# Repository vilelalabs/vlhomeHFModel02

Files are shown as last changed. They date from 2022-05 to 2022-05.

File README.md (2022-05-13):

# VLHOME Hardware Firmware - MODEL 02

Remotely activated device through Wifi connection with a Firebase database.

## Project

This software was developed to be used on ESP8266-12 (4Mb flash) microcontroller to controls a high voltage device and connecting to a physical activated switch.

## Operation

the device can be activated through three ways:

### > Application
Through using dedicated Application:  [VLHome App](https://github.com/vilelalabs/vlhome) 

### > Webpage
Through webpage using the addresses:

|Link |Function|
|:---:|:---:|
|http://device-IPAdress/|home page that confirms the connection|
|http://device-IPAdress/update|update through OTA|
|http://device-IPAdress/toggle|toggles the current state of the device|
|http://device-IPAdress/hostname|shows the host name of the device|

> example: http://192.168.1.225/update

### > Switch

Can be physically actvated bt the switch linked to CON1 (SWITCH) connector onboard (see images) - this connection is optional.

# Installation 

Until now (version: 1.0) its needed to use an auxiliar application from Espressif to connect the device to the local network. The application used is [EspTouch: SmartConfig for ESP ESP8266, ESP32](https://play.google.com/store/apps/details?id=com.khoazero123.iot_esptouch_demo). On it you will need to put the SSID and password information.

After some time the device is found and it shows the IP address, take note to use the webpage activation method, or even to compare to new device configuration screen (*Novo Dispositivo*) through [App](https://github.com/vilelalabs/vlhome).

From this point  **webpage** and **switch** methods can be used already , but on the **App**, you still need use the menu before: 

**Configurações > Dispositivos > Novo > Buscar Novo Dispositivo**

# Folder eaglefiles

In this folder you will find the necessary files for building the hardware board: 

- Eagle project
- Schematic file (SCH)
- Board file (PCB layout) (BRD) (between the two projects - one/two side only capacitor package is different)
- Bill of Materials file (BOM)
- PDF file with a ready-for-printing page with the board layout.
- MODEL_2_Gerber.zip for sent to a professinal fabrication

_* there is two versions for one side cooper and Double Layer  boards, see by file names_
# Images

## Schematic
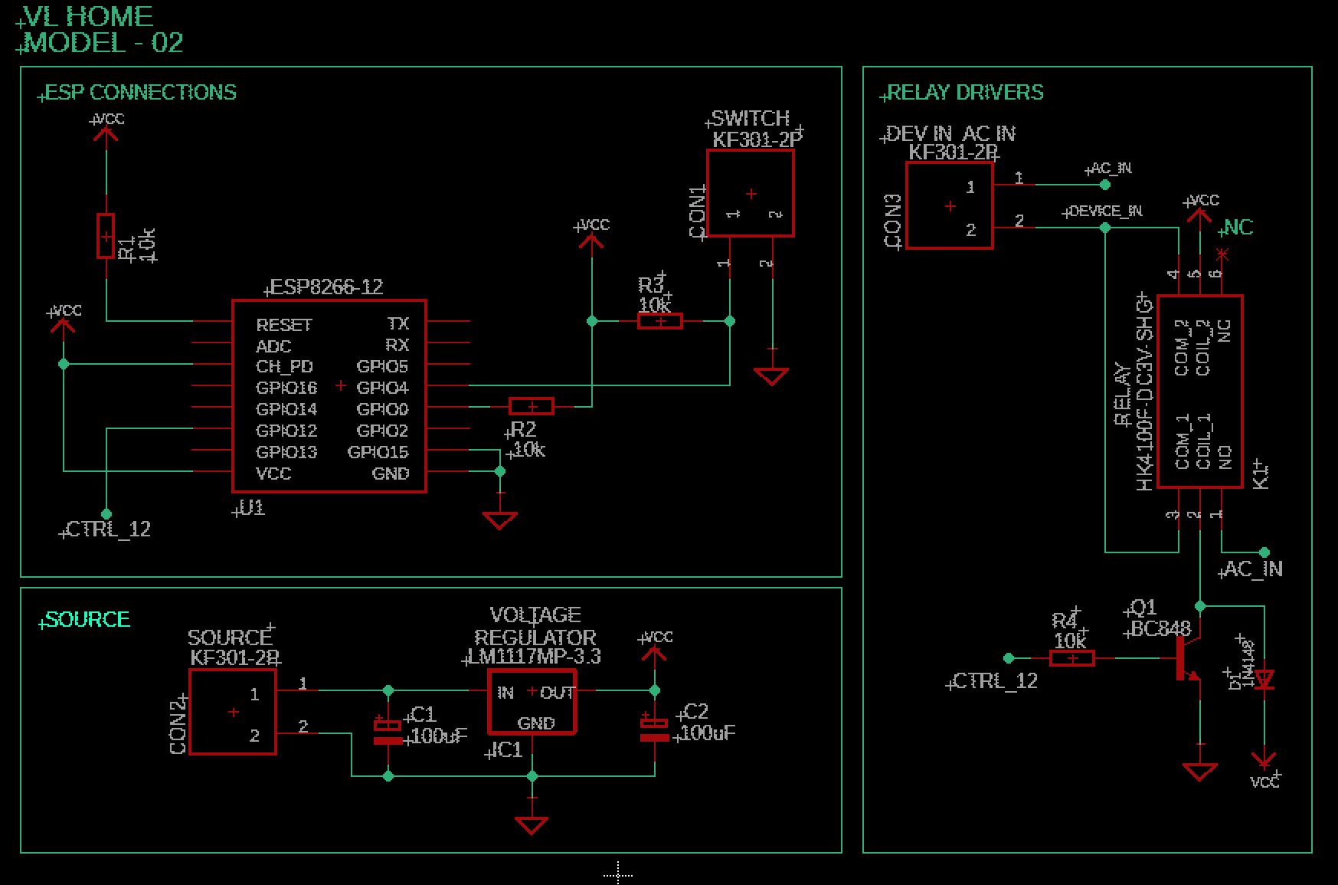
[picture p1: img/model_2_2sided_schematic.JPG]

## Board (PCB)
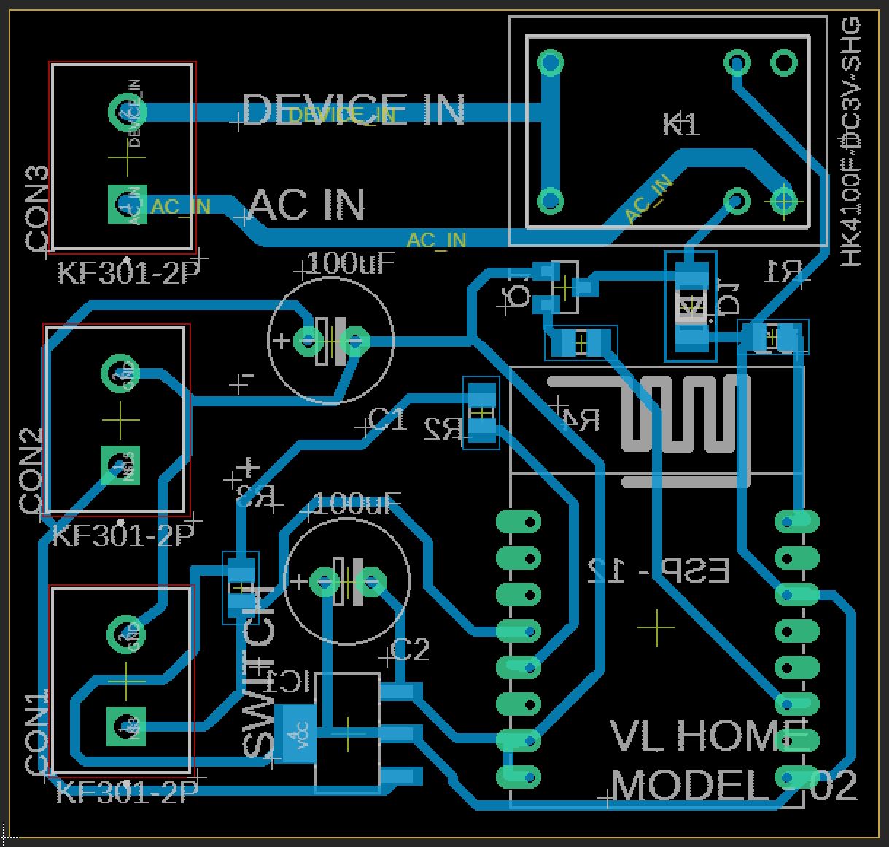
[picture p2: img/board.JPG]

### Double Layer  Board (PCB)
|Top Side |Bottom side|
|:---:|:---:|
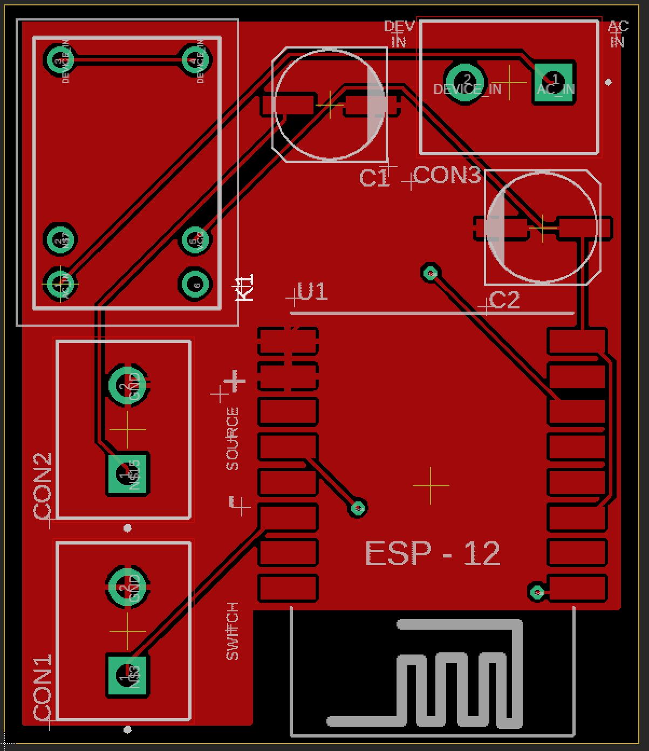
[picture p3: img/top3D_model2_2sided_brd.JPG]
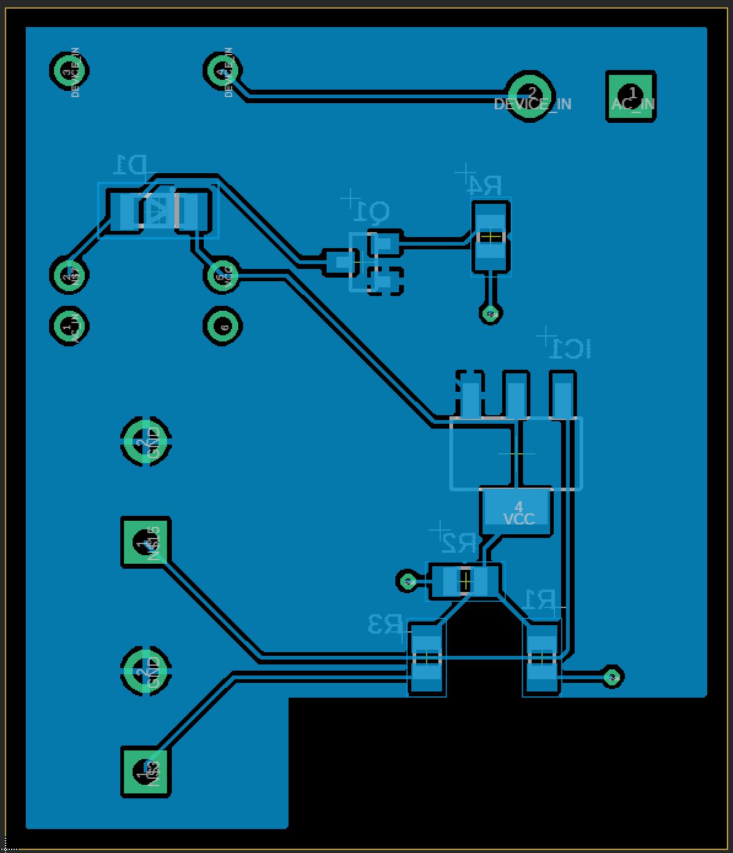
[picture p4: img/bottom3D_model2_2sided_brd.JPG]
|||
## 3D View
|Top Side - Single Cooper |Bottom side - Single Cooper|
|:---:|:---:|
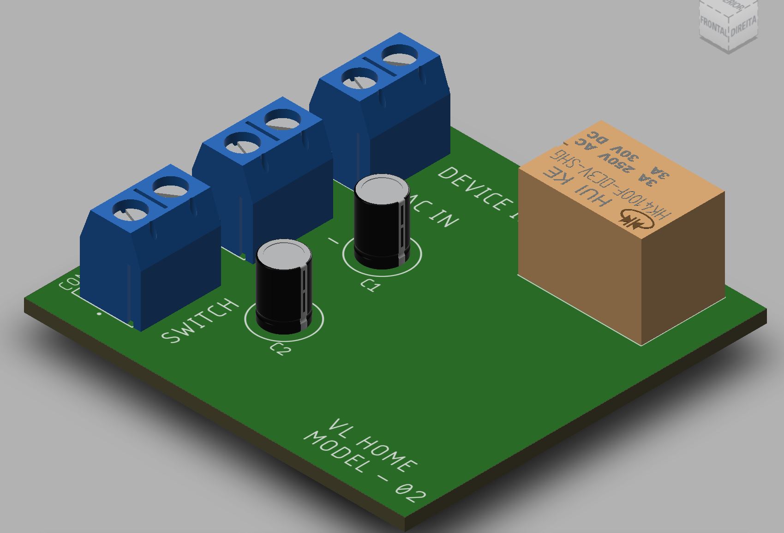
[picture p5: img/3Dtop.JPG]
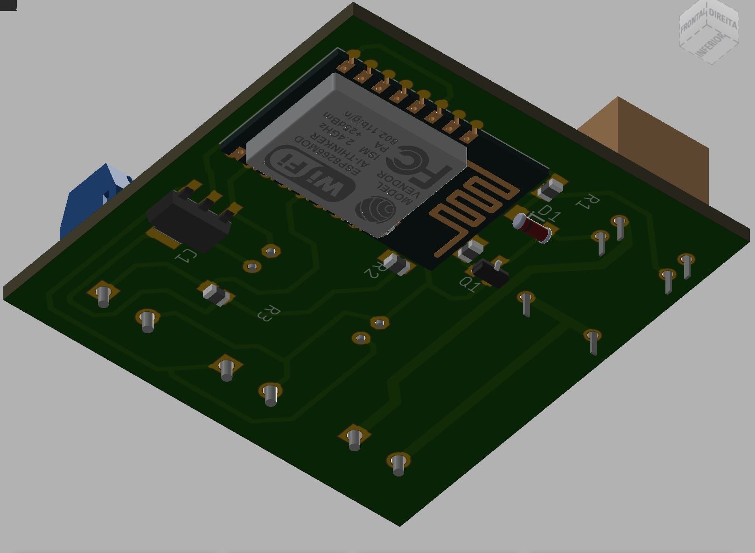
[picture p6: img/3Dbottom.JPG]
|||
|Top Side - Double Layer Cooper|Bottom side - Double Layer Cooper|
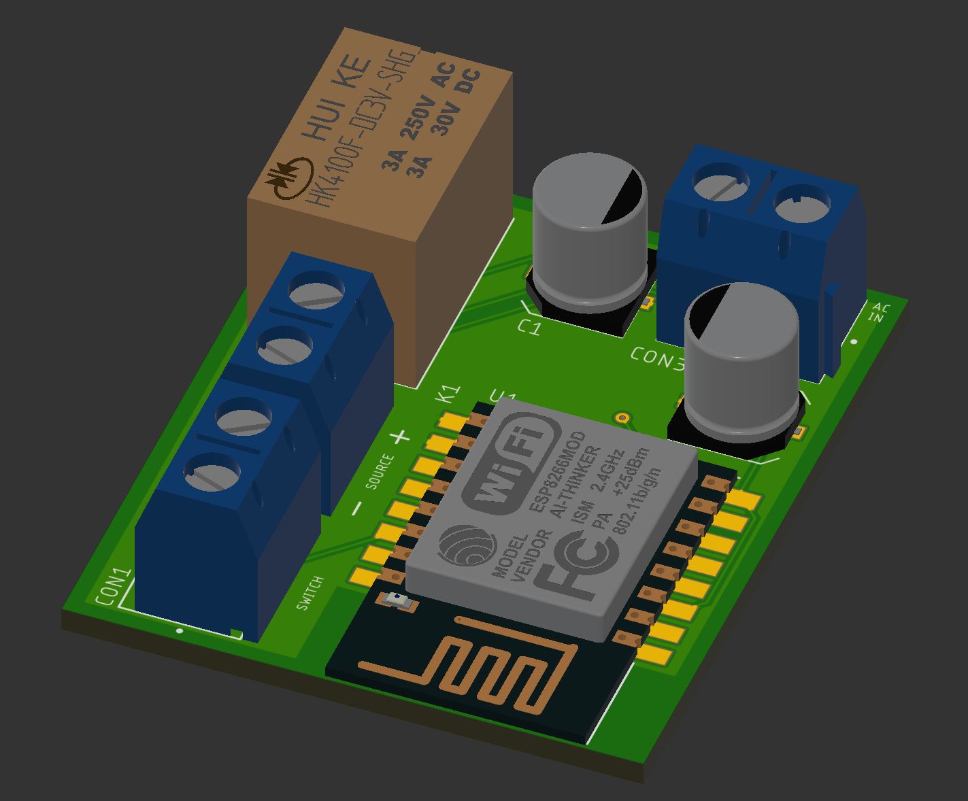
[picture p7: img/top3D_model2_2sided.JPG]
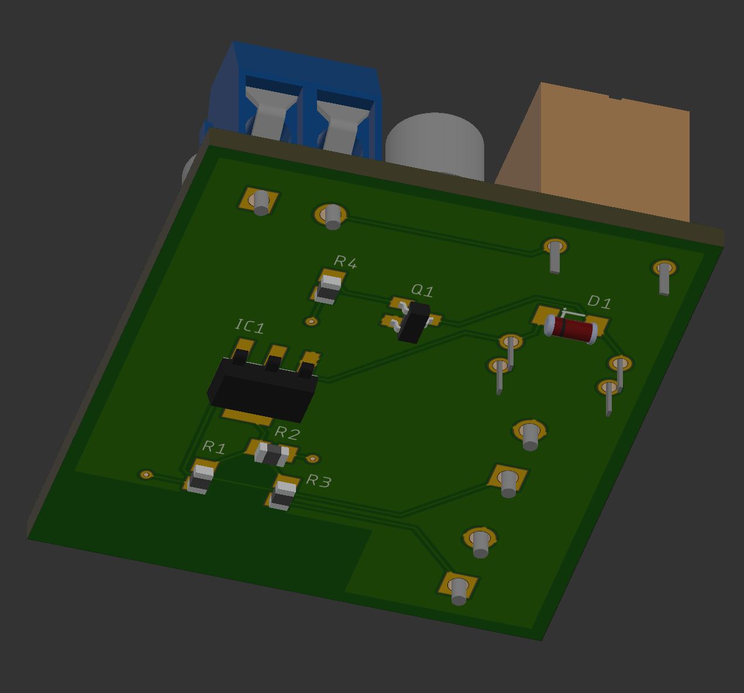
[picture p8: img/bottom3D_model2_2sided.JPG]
|||

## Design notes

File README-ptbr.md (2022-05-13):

_OBS: este arquivo pode estar desatualizado, sempre confira o README.md em inglês_

# VLHOME Hardware Firmware - MODEL 02

Dispositivo acionado remotamente via Wifi com conexão a banco de dados do Firebase

## Projeto

Este software foi desenvolvido para uso no microcontrolador ESP8266-12 (4Mb flash) para controle de um dispositivo de alta tensão e conexão de um interruptor de acionamento físico.

## Funcionamento

O dispositivo pode ser acionado por três modos diferentes:

### > Aplicativo
Através do uso de aplicativo próprio:  [VLHome App](https://github.com/vilelalabs/vlhome) 

### > Webpage
Através de webpage pelos dos endereços:

|Link |Função|
|:---:|:---:|
|http://IP-do-dispositivo/|home page confirmando a conexão|
|http://IP-do-dispositivo/update|atualização via OTA|
|http://IP-do-dispositivo/toggle|inverte o status atual do dispositivo|
|http://IP-do-dispositivo/hostname|mostra o host name do dispositivo|

> exemplo: http://192.168.1.225/update

### > Interruptor

Pode ser acionado fisicamente atráves do interruptor físico ligado ao conector CON1 (SWITCH) na placa (ver imagens) - a conexão deste interruptor é opcional.

# Instalação e Habilitação

Até o momento (versão 1.0) é necessário usar um aplicativo auxiliar da Espressif para que o novo dispositivo seja conectado na rede local. O aplicativo utilizado é o [EspTouch: SmartConfig for ESP ESP8266, ESP32](https://play.google.com/store/apps/details?id=com.khoazero123.iot_esptouch_demo). Nele você irá inserir a SSID da rede e a senha.

Após um período o dispositivo é localizado e o IP é exibido, tome nota do mesmo para utilizar o método de acionamento via webpage, ou mesmo para comparar no reconhecimento do *Novo Dispositivo* via [App](https://github.com/vilelalabs/vlhome).

A partir deste ponto já podem ser utilizados os métodos de acionamento via **webpage** e **interruptor**, porém para uso no **App** o dispositivo deve ser localiza-lo no smartphone utilizando o menu: 

**Configurações > Dispositivos > Novo > Buscar Novo Dispositivo**

# Pasta eaglefiles

Nesta pasta poderão ser encontrados os arquivos necessários para execução eletrônica do hardware:

- Projeto do Eagle
- Arquivo de Esquemático (SCH)
- Arquivo da placa (BRD)
- Arquivo com a lista de componentes (BOM)
- Arquivo PDF pronto para impressão do Layout da placa
- MODEL_2_Gerber.zip  para envio para fabricação profissional

# Imagens

## Esquemático
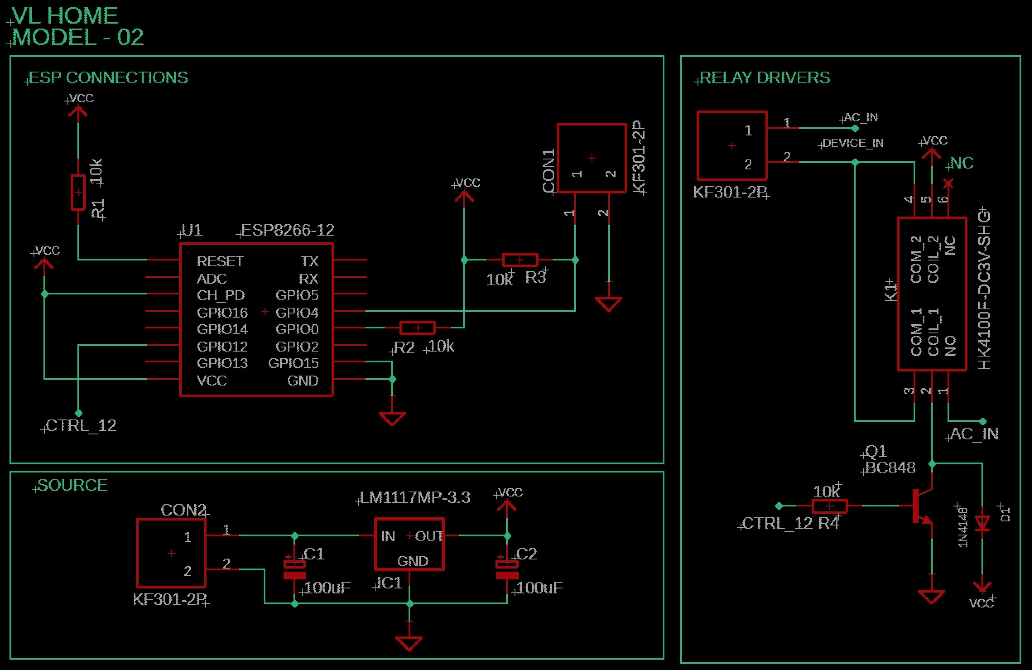
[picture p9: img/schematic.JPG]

## Placa (PCB)

## 3D
|Superior |Inferior|
|:---:|:---:|
|||

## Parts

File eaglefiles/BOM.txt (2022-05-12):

Part List

Part Value            Device           Package          Description                                  
C1   100uF            CPOL-EUE2.5-7    E2,5-7           POLARIZED CAPACITOR, European symbol         
C2   100uF            CPOL-EUE2.5-7    E2,5-7           POLARIZED CAPACITOR, European symbol         
CON1 KF301-2P         KF301-2P         KF301-2P         2 Pin Terminal Block 5mm Pitch Check prices  
CON2 KF301-2P         KF301-2P         KF301-2P         2 Pin Terminal Block 5mm Pitch Check prices  
CON3 KF301-2P         KF301-2P         KF301-2P         2 Pin Terminal Block 5mm Pitch Check prices  
D1   1N4148           LL4148           SOD80            1N4148 General Purpose Rectifie              
IC1  LM1117MP-3.3     LM1117MP-3.3     SOT223           800mA Low-Dropout Linear Regulator           
K1   HK4100F-DC3V-SHG HK4100F-DC3V-SHG HK4100FDC3VSHG   Relays Gen Purpose 3.3VDC SPDT 3A (250VAC , 30VDC)
Q1   BC848            BC848            SOT23            NPN TRANSISTOR                              
R1   10k              R-EU_R0805       R0805            RESISTOR, European symbol                        
R2   10k              R-EU_R0805       R0805            RESISTOR, European symbol                        
R3   10k              R-EU_R0805       R0805            RESISTOR, European symbol                        
R4   10k              R-EU_R0805       R0805            RESISTOR, European symbol                        
U1   ESP8266-12       ESP12F           ESP12F           ESP8266 12F SMD mount

* R1, R2 and R3 can be changed for similar values when mounting.
* for double sided board is used SMD capacitors with [6.3 x 7.7] package dimensions

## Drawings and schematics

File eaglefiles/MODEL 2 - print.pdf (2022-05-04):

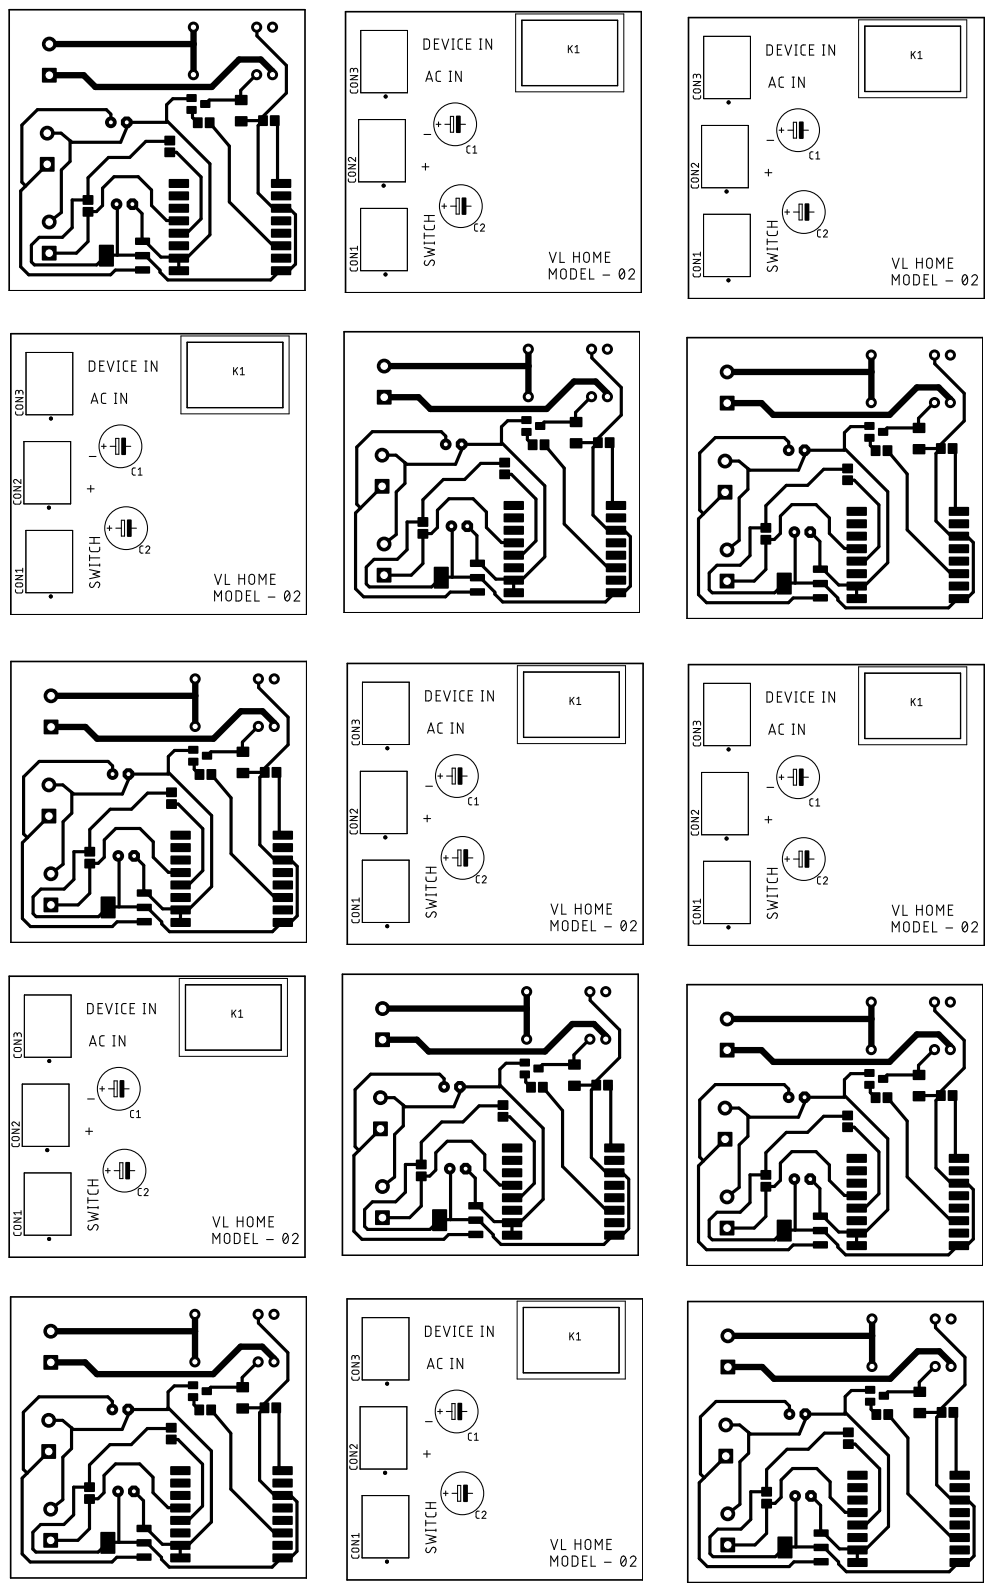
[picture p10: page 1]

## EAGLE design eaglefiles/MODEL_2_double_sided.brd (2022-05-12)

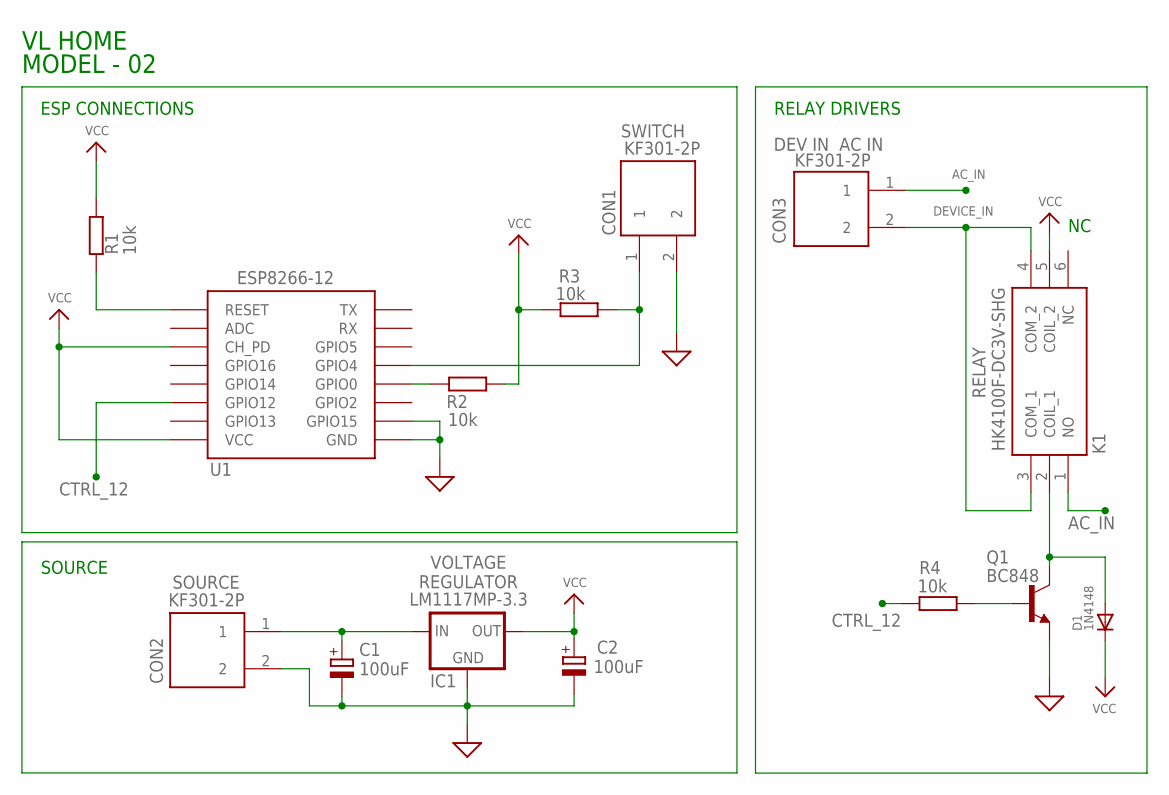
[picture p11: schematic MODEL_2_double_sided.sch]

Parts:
C1, C2: 100uF; UD-6,3X7,7_NICHICON
CON1, CON2, CON3: KF301-2P; HANDSON_KF301-2P
D1: 1N4148; SOD80_DO213AA_MINIMELF
IC1: LM1117MP-3.3; SOT223
K1: HK4100F-DC3V-SHG; HK4100FDC5VSHG
Q1: BC848; SOT23
R1, R2, R3, R4: 10k; R0805
U1: ESP8266-12; ESP12-SMD

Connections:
AC_IN: CON3.1, K1.1 (NO)
CTRL_12: R4.2, U1.GPIO12
DEVICE_IN: CON3.2, K1.3 (COM_1), K1.4 (COM_2)
GND: C1.-, C2.-, CON1.2, CON2.2, IC1.1 (GND), Q1.2 (E), U1.GND, U1.GPIO15
unnamed: R1.1, U1.RESET
unnamed: CON1.1, R3.1, U1.GPIO4
unnamed: Q1.1 (B), R4.1
unnamed: R2.1, U1.GPIO0
unnamed: D1.A, K1.2 (COIL_1), Q1.3 (C)
unnamed: C1.+, CON2.1, IC1.3 (IN)
VCC: C2.+, D1.C, IC1.2 (OUT), IC1.4 (OUT), K1.5 (COIL_2), R1.2, R2.2, R3.2, U1.CH_PD, U1.VCC

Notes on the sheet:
ESP CONNECTIONS
SOURCE
RELAY DRIVERS
MODEL - 02
VL HOME
SWITCH
CON3
DEV IN AC IN
RELAY
VOLTAGE REGULATOR

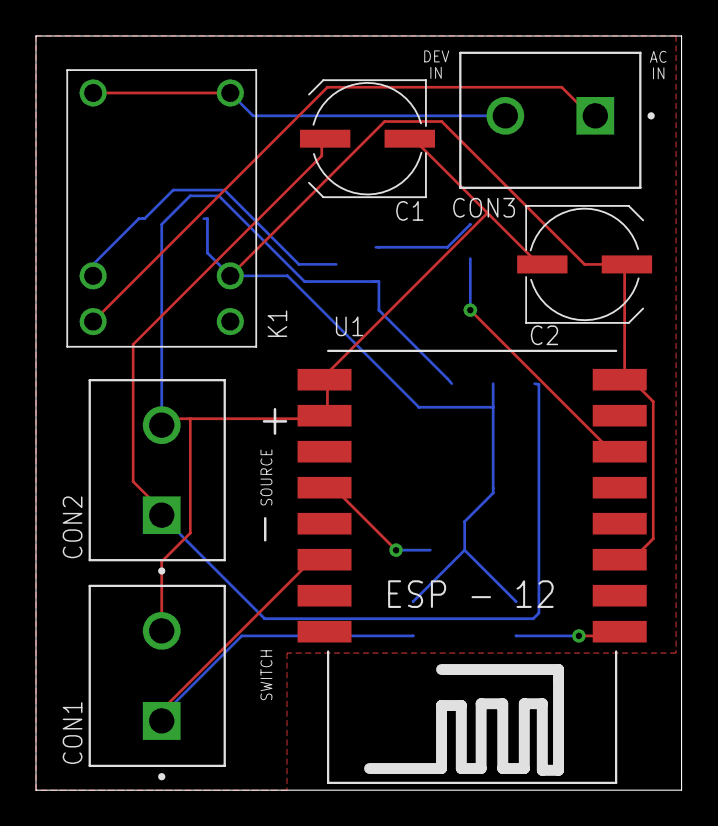
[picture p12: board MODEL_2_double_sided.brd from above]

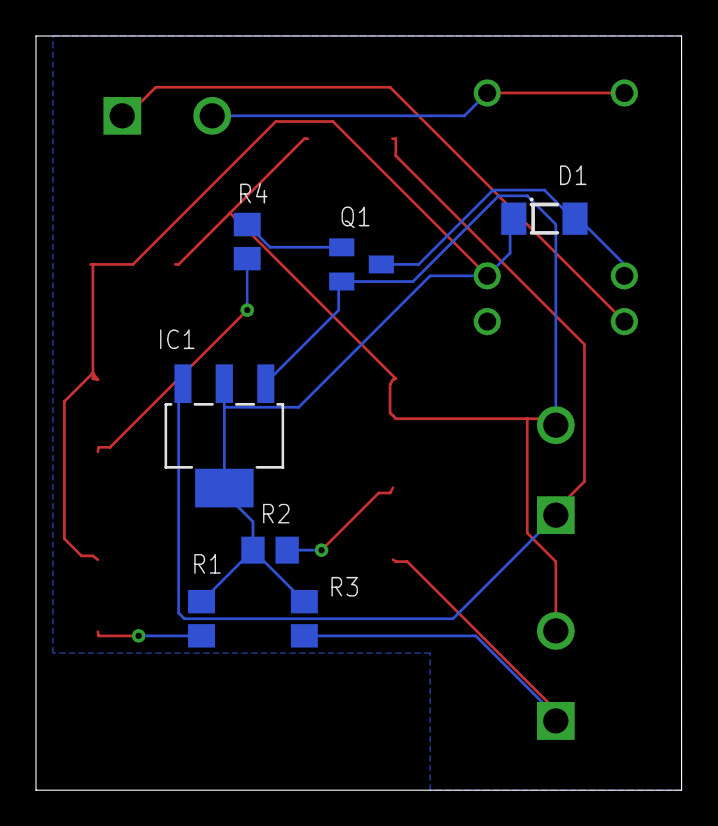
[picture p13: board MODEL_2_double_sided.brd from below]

Board: 2 copper layers, 35.9 x 41.9 mm, 14 parts (7 on the bottom side), 11 nets.

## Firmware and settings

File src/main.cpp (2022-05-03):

/*
  Main.cpp
  VLHome Hardware Firmware - Model 02

  @author:    Henrique Vilela
  @version:   1.0
  @date:      2022-04-24

  @description:
    This code is exclusive for Model 02 VLHome Hardware.
    Controls:
      - 01 Relay on GPIO12 of ESP8266-12F board.
      - 01 Switch on GPIO04 of ESP8266-12F board.

 */

#include <Arduino.h>

#include "ESPWiFiWebUpdate.h"
#include "FireBaseAccess.h"

#define CTRL_PIN 12
#define SWITCH_PIN 4
#define TYPE "light"
#define START_VALUE "Apagada"

// global variables
bool switchStatus = false;

// functions prototypes
void initializePages();

void setup() {
  String ipAddress = ESPWiFiWebUpdateSetup();
  initializePages();

  pinMode(CTRL_PIN, OUTPUT);
  pinMode(SWITCH_PIN, INPUT);

  if (!FireBaseAccessSetup(ipAddress)) {
    newDeviceKey(ipAddress, TYPE, START_VALUE);
    Serial.println("Device not found on Firebase, adding a new device!");
    Serial.println("Restarting...");
    delay(4000);
    ESP.restart();
    delay(1000);
  }
  // update the device value with the current status on Firebase
  // readValue(CTRL_PIN); startValue(CTRL_PIN)????
}
//------------------------------------------------------------------------------

void loop() {
  ESPWiFiWebUpdateLoop();
  FireBaseAccessLoop(CTRL_PIN);

  if (digitalRead(SWITCH_PIN) != switchStatus) {
    toggleDeviceValue(CTRL_PIN);
    switchStatus = !switchStatus;
  }
}

//------------------------------------------------------------------------------
void initializePages() {
  // páginas de acionamento do dispositivo via web
  httpServer.on("/toggle", []() {
    toggleDeviceValue(CTRL_PIN);
    httpServer.send(
        200, "text/plain",
        digitalRead(CTRL_PIN) ? " Lampada Acesa" : "Lampada Apagada");
  });
  // para dispositivos apenas ON/OFF --------------------------------
  httpServer.on("/statusCTRL_PIN", []() {
    String msg;
    msg += digitalRead(CTRL_PIN) ? "CTRL_PIN_ON" : "CTRL_PIN_OFF";
    httpServer.send(200, "text/plain", msg);
  });
}

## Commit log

2022-04-26 changing switch input to pin 5
2022-04-26 change switch to pin 5
2022-05-04 Eagle files upload
    [MODEL_2.brd, MODEL_2.sch]
2022-05-04 adding BOM to files
2022-05-04 update BOM
2022-05-12 double sided project files upload
    [MODEL_2_double_sided.brd, MODEL_2_double_sided.sch]
2022-05-12 Added double sided board files and images
2022-05-13 Add gerber file
